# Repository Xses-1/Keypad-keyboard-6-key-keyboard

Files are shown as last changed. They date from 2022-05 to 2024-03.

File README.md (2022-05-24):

# Arrow Pad Keyboard


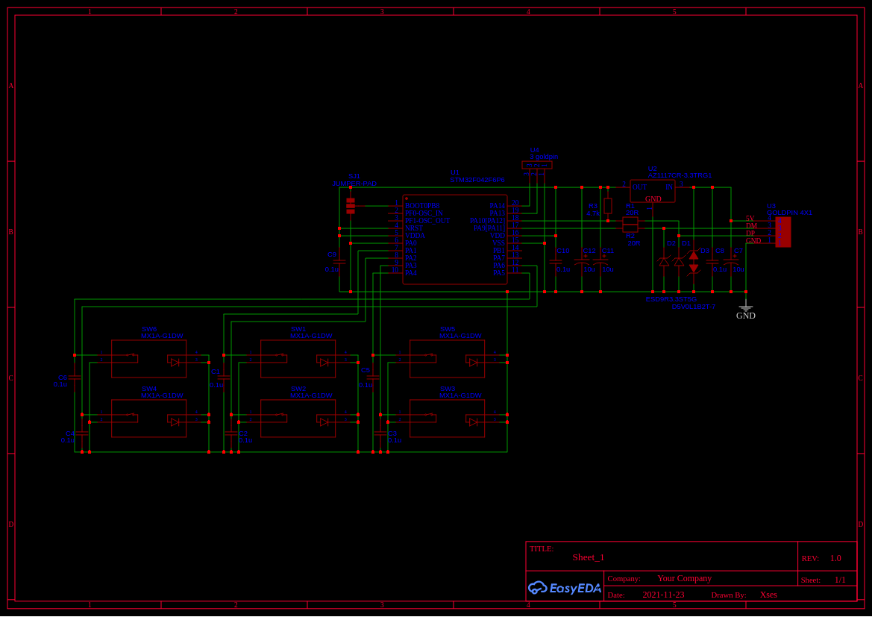
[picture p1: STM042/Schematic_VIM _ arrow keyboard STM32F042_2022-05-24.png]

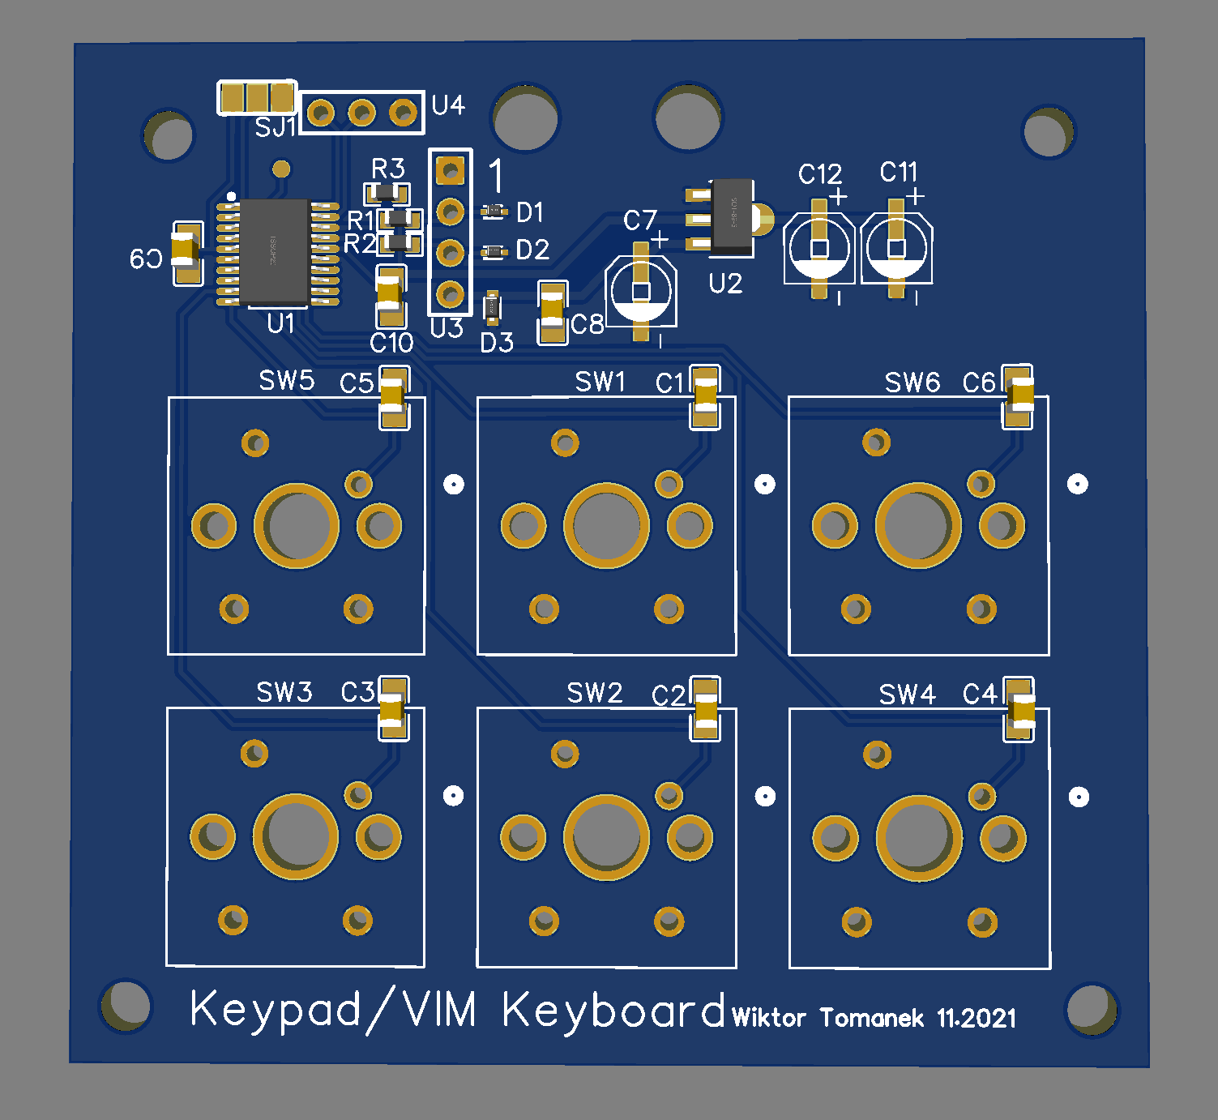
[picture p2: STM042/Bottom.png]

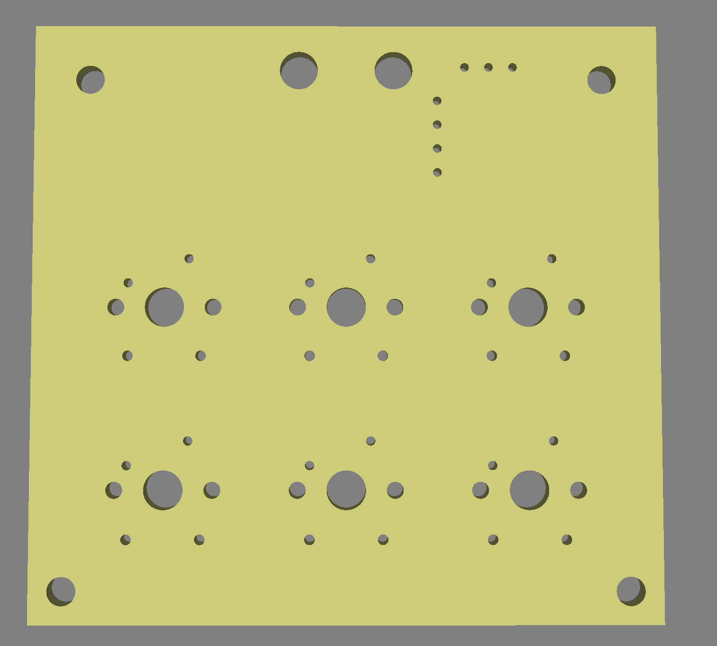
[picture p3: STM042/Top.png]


There are 2 versions of PCB design due to chip shortage.
* STM32F042F
* STM32F042G

Directory "Firmware" contains usbd_hid.c file which contains custom USB descriptor, usbd_hid.h which contains USB configuration, Keypad_keyboard.ioc which is configuration file for STM32Cube IDE, and main.c which is self explenatory.

All THT compoents should be on the top side (without solder mask) and all the SMD on the bottom side. U4 is ST-Link programmer socket U3 is USB socket.

Directory "Case" contains Keypad_Keyboard_Case.FCStd which is FreeCAD project and prepared STL files that can be directly sliced and printed.

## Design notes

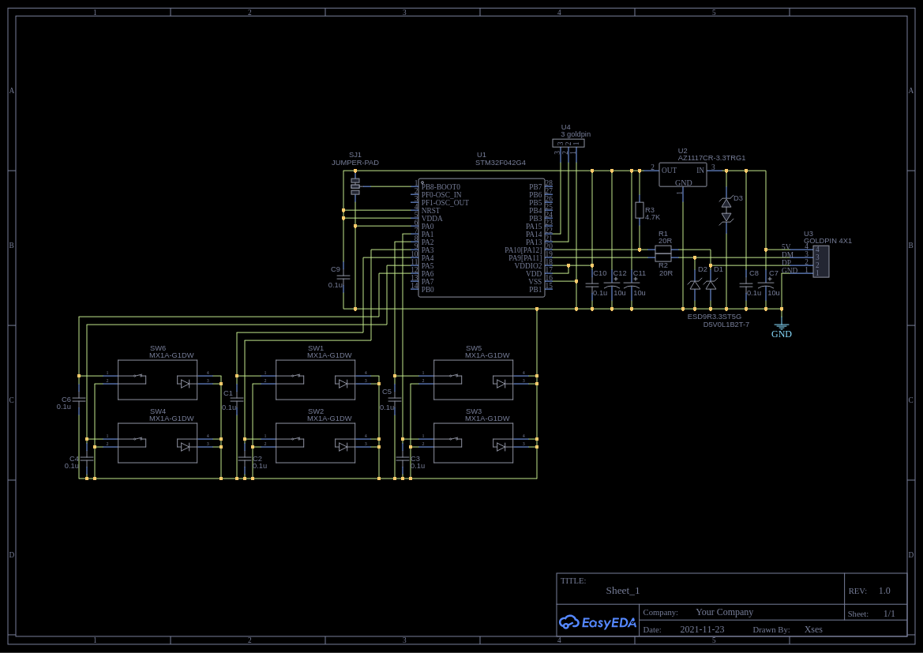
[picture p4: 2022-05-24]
STM32F042G/Schematic_VIM _ arrow keyboard STM32F042G_2022-05-24.png

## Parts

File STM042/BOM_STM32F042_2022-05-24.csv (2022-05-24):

ID | Name | Designator | Footprint | Quantity
1 | 0.1u | C1,C2,C3,C4,C5,C6,C8,C9,C10 | C0805 | 9
2 | 10u | C7,C11,C12 | SMD-ECAP-4X5.3 | 3
3 | ESD9R3.3ST5G | D1,D2 | SOD-923_L0.8-W0.6-LS1.0-RD | 2
4 | D5V0L1B2T-7 | D3 | SOD-523_L1.2-W0.8-LS1.6-BI | 1
5 | 20R | R1,R2 | R0603 | 2
6 | 4.7k | R3 | R0603 | 1
7 | JUMPER-PAD | SJ1 | PAD-JUMPER-3-FIXED | 1
8 | MX1A-G1DW | SW1,SW2,SW3,SW4,SW5,SW6 | MX1A-G1DW_CHY_SINGLESIDE | 6
9 | STM32F042F6P6 | U1 | TSSOP-20_L6.5-W4.4-P0.65-LS6.4-BL | 1
10 | AZ1117CR-3.3TRG1 | U2 | SOT-89-3_L4.5-W2.5-P1.50-LS4.2-BR | 1
11 | GOLDPIN 4X1 | U3 | GOLDPIN 4X1 | 1
12 | 3 goldpin | U4 | 3 GOLDPIN | 1

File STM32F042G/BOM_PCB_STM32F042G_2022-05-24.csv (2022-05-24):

ID | Name | Designator | Footprint | Quantity
1 | JUMPER-PAD | SJ1 | PAD-JUMPER-3-FIXED | 1
2 | 0.1u | C1,C2,C3,C4,C5,C6,C8,C9,C10 | C0805 | 9
3 | 10u | C7,C11,C12 | SMD-ECAP-4X5.3 | 3
4 | AZ1117CR-3.3TRG1 | U2 | SOT-89-3_L4.5-W2.5-P1.50-LS4.2-BR | 1
5 | GOLDPIN 4X1 | U3 | GOLDPIN 4X1 | 1
6 | 3 goldpin | U4 | 3 GOLDPIN | 1
7 | ESD9R3.3ST5G | D1,D2 | SOD-923_L0.8-W0.6-LS1.0-RD | 2
8 | D5V0L1B2T-7 | D3 | SOD-523_L1.2-W0.8-LS1.6-BI | 1
9 | 20R | R1,R2 | R0603 | 2
10 | 4.7K | R3 | R0603 | 1
11 | STM32F042G4 | U1 | UFQFPN-28_L4.0-W4.0-P0.50-BL | 1
12 | MX1A-G1DW | SW1,SW2,SW3,SW4,SW5,SW6 | MX1A-G1DW_CHY_SINGLESIDE | 6

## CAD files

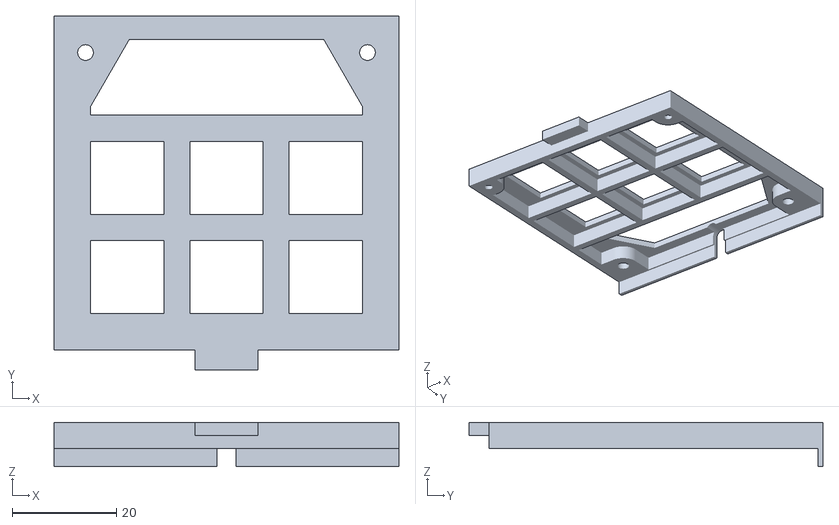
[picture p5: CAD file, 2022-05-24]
Case/the_case-MeshesFrame (Meshed).stl
66.0 x 67.8 x 8.50

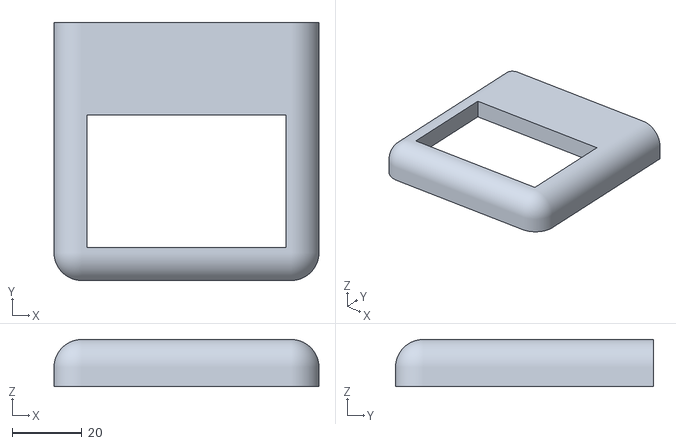
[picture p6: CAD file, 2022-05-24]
Case/the_case-MeshesTop (Meshed).stl
76.0 x 74.0 x 13.5

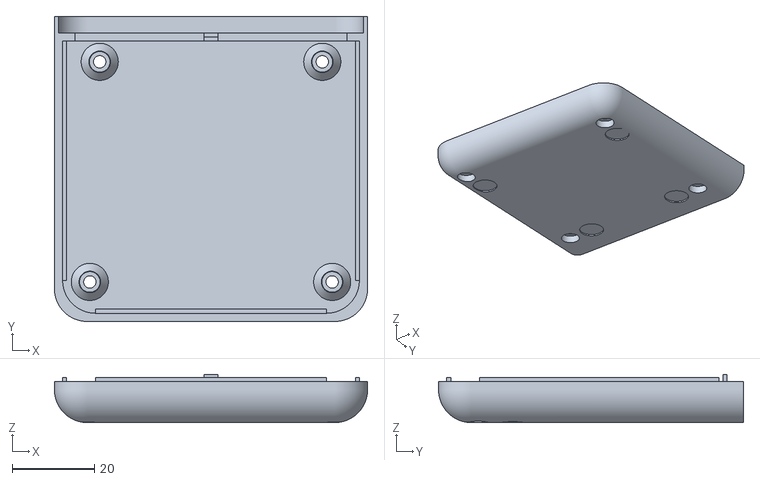
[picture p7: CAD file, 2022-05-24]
Case/the_case-MeshesBottom (Meshed).stl
76.0 x 74.0 x 11.7

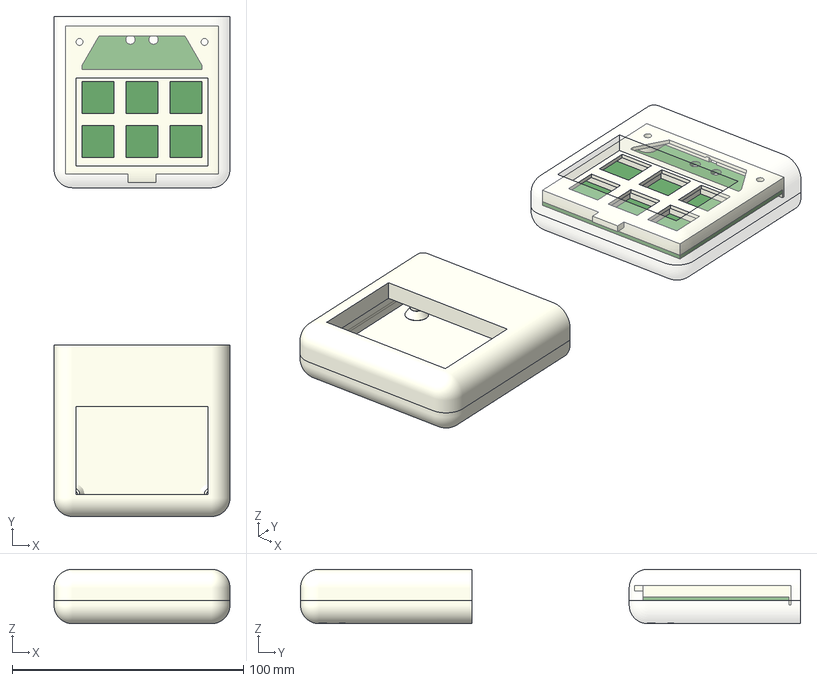
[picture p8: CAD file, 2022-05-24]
Case/Kaypad_Keyboard_Case.FCStd
76.0 x 216.0 x 23.5 mm
PCB
Frame
Bottom
Top
Bottom (Meshed)
Top (Meshed)

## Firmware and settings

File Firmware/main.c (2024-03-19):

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
/* Includes ------------------------------------------------------------------*/
#include "main.h"
#include "usb_device.h"

/* USER CODE BEGIN Includes */

#include <stdbool.h>

/* USER CODE END Includes */

/* USER CODE BEGIN PTD */

extern USBD_HandleTypeDef hUsbDeviceFS;

/* USER CODE END PTD */

TIM_HandleTypeDef htim2;
TIM_HandleTypeDef htim3;

/* USER CODE BEGIN PV */

struct KEYS {

	uint16_t SW_State[6];
	uint8_t	 Pressed[6];
	bool	 SW_Key[6];

} keys;

struct keyboardHID_t {

	uint8_t id;
	uint8_t modifiers;
	uint8_t key1;
	uint8_t key2;
	uint8_t key3;

} keyboardHID;

/* USER CODE END PV */

void SystemClock_Config(void);
static void MX_GPIO_Init(void);
static void MX_TIM2_Init(void);
static void MX_TIM3_Init(void);
/* USER CODE BEGIN PFP */

uint8_t USBD_HID_SendReport(USBD_HandleTypeDef  *pdev,
                            uint8_t *report,
                            uint16_t len);

/* USER CODE END PFP */

/**
  * @brief  The application entry point.
  * @retval int
  */
int main(void)
{
  /* USER CODE BEGIN 1 */

	for (int i = 0; i < 6; i++) {

		keys.SW_State[i] = 0;
		keys.SW_Key[i] 	 = 0;
		keys.Pressed[i]	 = 0;

	}

	keyboardHID.id = 1;
	keyboardHID.modifiers = 0;
	keyboardHID.key1 = 0;
	keyboardHID.key2 = 0;
	keyboardHID.key3 = 0;

  /* USER CODE END 1 */

  /* MCU Configuration--------------------------------------------------------*/

  /* Reset of all peripherals, Initializes the Flash interface and the Systick. */
  HAL_Init();

  /* Configure the system clock */
  SystemClock_Config();

  /* Initialize all configured peripherals */
  MX_GPIO_Init();
  MX_TIM2_Init();
  MX_TIM3_Init();
  MX_USB_DEVICE_Init();
  /* USER CODE BEGIN 2 */

  HAL_TIM_Base_Start_IT(&htim2);
  HAL_TIM_Base_Start_IT(&htim3);

  /* USER CODE END 2 */

  /* Infinite loop */
  /* USER CODE BEGIN WHILE */
  while (1)
  {

    /* USER CODE END WHILE */

    /* USER CODE BEGIN 3 */
  }
  /* USER CODE END 3 */
}

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
/* USER CODE BEGIN 4 */

void HAL_TIM_PeriodElapsedCallback(TIM_HandleTypeDef* htim) {

	if (htim == &htim2) {
		keys.SW_Key[0] = HAL_GPIO_ReadPin(GPIOA, SW1_Pin);
		keys.SW_Key[1] = HAL_GPIO_ReadPin(GPIOA, SW2_Pin);
		keys.SW_Key[2] = HAL_GPIO_ReadPin(GPIOA, SW3_Pin);
		keys.SW_Key[3] = HAL_GPIO_ReadPin(GPIOA, SW4_Pin);
		keys.SW_Key[4] = HAL_GPIO_ReadPin(GPIOA, SW5_Pin);
		keys.SW_Key[5] = HAL_GPIO_ReadPin(GPIOA, SW6_Pin);

		/**** The bouncing ****/
		for (int i = 0; i < 6; i++) {
			keys.SW_State[i] = (keys.SW_State[i] << 1) | keys.SW_Key[i] | 0xe000;
		}

		HAL_TIM_Base_Start_IT(&htim2);
	}

	if (htim == &htim3) {

		/**** Which key was pressed ****/

		/* If you want to change the keys:
		 *
		 * Universal Serial Bus HID Usage Tables
		 * Pages 53-59
		 *
		 * 11 - H
		 * 13 - J
		 * 14 - K
		 * 15 - L
		 *
		 * 4  - A
		 * 7  - D
		 * 22 - S
		 * 26 - W
		 *
		 * 40 - Enter
		 * 41 - Escape
		 * 55 - Dot
		 *
		 */

		for (int i = 0; i < 6; i++) {
			if (keys.SW_State[i] == 0xe000) {
				switch (i) {
					case 0 :
						keys.Pressed[i] = 82; //Up
						break;

					case 1 :
						keys.Pressed[i] = 81; //Down
						break;

					case 2 :
						keys.Pressed[i] = 79; //Right
						break;

					case 3 :
						keys.Pressed[i] = 80; //Left
						break;

					case 4 :
						keys.Pressed[i] = 40; //Enter
						break;

					case 5 :
						keys.Pressed[i] = 41; //Escape
						break;
				}
			} else {
				keys.Pressed[i] = 0;
			}
		}

		for (int i = 0, j = 0; i < 6 && j < 3; i++) {
			if (keys.Pressed[i] != 0) {
				switch (j) {
					case 0 :
						keyboardHID.key1 = keys.Pressed[i];
						break;

					case 1 :
						keyboardHID.key2 = keys.Pressed[i];
						break;

					case 2 :
						keyboardHID.key3 = keys.Pressed[i];
						break;
				}

				j++;
			}
		}

		/**** Sending USB Report to the Host Device ****/
		USBD_HID_SendReport(&hUsbDeviceFS, &keyboardHID, sizeof(struct keyboardHID_t));

		keyboardHID.key1 = 0;
		keyboardHID.key2 = 0;
		keyboardHID.key3 = 0;

		HAL_TIM_Base_Start_IT(&htim3);
	}
}

/* USER CODE END 4 */
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


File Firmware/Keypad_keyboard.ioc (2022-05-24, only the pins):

Mcu.UserName=STM32F042F4Px
PA1.GPIO_Label=SW1(UP)
PA1.Signal=GPIO_Input
PA11.Signal=USB_DM
PA12.Signal=USB_DP
PA13.Signal=SYS_SWDIO
PA14.Signal=SYS_SWCLK
PA2.GPIO_Label=SW2(DOWN)
PA2.Signal=GPIO_Input
PA3.GPIO_Label=SW3(RIGHT)
PA3.Signal=GPIO_Input
PA4.GPIO_Label=SW5(DOT)
PA4.Signal=GPIO_Input
PA5.GPIO_Label=SW6(ESC)
PA5.Signal=GPIO_Input
PA6.GPIO_Label=SW4(LEFT)
PA6.Signal=GPIO_Input

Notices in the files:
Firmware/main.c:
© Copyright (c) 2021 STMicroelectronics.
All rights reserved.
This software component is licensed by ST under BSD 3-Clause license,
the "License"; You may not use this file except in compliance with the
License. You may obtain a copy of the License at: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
